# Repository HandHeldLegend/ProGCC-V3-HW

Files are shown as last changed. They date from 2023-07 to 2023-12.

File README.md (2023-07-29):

# ProGCC V3 HW
This is the official Github page for the ProGCC V3 hardware from Hand Held Legend.

## PCB Design License
<br />This PCB design (includes the layout of traces, footprints, and PCB board layout) is licensed under a <a rel="license" href="http://creativecommons.org/licenses/by-nc-sa/3.0/">Creative Commons Attribution-NonCommercial-ShareAlike 3.0 Unported License</a>.

## PCB Schematic License
This PCB schematic is licensed under a <a rel="license" href="https://ohwr.org/cern_ohl_s_v2.pdf">CERN-OHL-S Strongly Reciprocal License</a>.<br>
It contains elements derived from [PhobGCC Hardware](https://github.com/PhobGCC/PhobGCC-HW/) including the rumble schematic and choice of ADCs.

## Shop Links
- [TBA](https://handheldlegend.com)

## Detailed Information
All of our guides on assembly, updating the firmware, and operation
are listed on [our Wiki page linked here](https://wiki.handheldlegend.com).

## Features
- TBA

## Attributions
- Partial trace layout work and initial prototyping performed by [Esca](https://github.com/ESCA47/).
- Main PCB, button board PCB, and bulk schematic designed by Mitch Cairns.
- Rumble schematic derived from work created by the [PhobGCC Team](https://github.com/PhobGCC/).

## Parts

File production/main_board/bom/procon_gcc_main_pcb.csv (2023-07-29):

Id | Designator | Footprint | Quantity | Designation | Supplier and ref
1 | SW4 | TS35CA | 1 | TS35CA
2 | U2,U3,U1,U4 | GH39F | 4 | GH39F (Hall SOT23)
3 | R2,R4 | R_0402_1005Metric | 2 | 100R
4 | R29,R30 | R_0402_1005Metric | 2 | 27
5 | L2,L7,L5,L4,L6,L3,L8,L1 | SK6805-EC-15 | 8 | SK6805-EC-15
6 | D1 | D_SOD-123 | 1 | M7C
7 | C6,C5,C14,C7 | C_0603_1608Metric | 4 | 100nF
8 | TP14,TP13,TP15,TP1,TP11,TP4,TP16,TP3,TP2,TP9,TP7,TP8,TP5 | TestPoint_Pad_D1.5mm | 13 | TestPoint
9 | R18,R14,R17,R16,R19,R15 | R_0402_1005Metric | 6 | 1k
10 | U8,U10 | SOIC-8_3.9x4.9mm_P1.27mm | 2 | MCP3002
11 | C10,C12,C11,C9 | C_0603_1608Metric_Pad1.08x0.95mm_HandSolder | 4 | .047u
12 | Q6,Q4,Q5 | SOT-23 | 3 | BSS138
13 | R22 | R_0402_1005Metric | 1 | 330
14 | F3,F2,F1 | Fuse_1206_3216Metric_Pad1.42x1.75mm_HandSolder | 3 | Fuse
15 | R7,R6,R11,R12,R13,R10 | R_0603_1608Metric_Pad0.98x0.95mm_HandSolder | 6 | 1k
16 | Q3,Q2 | SOT-23 | 2 | Q_NMOS_GSD
17 | C1,C17,C18,C21,C22,C13 | C_0402_1005Metric | 6 | 100n
18 | U6 | QFN-56-1EP_7x7mm_P0.4mm_EP3.2x3.2mm | 1 | RP2040
19 | C19 | C_0402_1005Metric | 1 | 1u
20 | D4,D2 | D_SOD-323_HandSoldering | 2 | CUS08F30
21 | R5,R21,R1,R3 | R_0402_1005Metric | 4 | 10k
22 | C8 | C_0603_1608Metric | 1 | 10u
23 | Y1 | Resonator_SMD_Murata_CSTxExxV-3Pin_3.0x1.1mm | 1 | Crystal_GND3
24 | C3 | CP_EIA-3216-18_Kemet-A | 1 | 47uF 6.3v
25 | U7 | SOT-23 | 1 | LP3986-33B3F
26 | SW2,SW1 | GL18 | 2 | GL18_SW
27 | REF** | HHL_Logo | 1 | HHL_Logo
28 | SW3 | SW_TS-1187A-B-A-B | 1 | TS-1187A-B-A-B
29 | C2,C4 | C_0603_1608Metric | 2 | 2.2uF
30 | J3 | molex_5051101492_14P | 1 | To Button Board
31 | Q1 | SOT-23 | 1 | Q_PMOS_GDS
32 | J9 | Shou Han Type-C 24P QCHT | 1 | USB_C_Receptacle
33 | U9 | SOIC-8_5.23x5.23mm_P1.27mm | 1 | W25Q128JVS
34 | U11,U5 | LGA14 | 2 | ST_LSM6
35 | R9,R8 | R_0603_1608Metric_Pad0.98x0.95mm_HandSolder | 2 | 5.1k
36 | R20 | R_0402_1005Metric | 1 | 500K

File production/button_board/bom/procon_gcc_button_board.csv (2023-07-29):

# | Reference | Qty | Value | Footprint | DNP | MPN
1 | D1, D2, D3, D4, D5, D6 | 6 | BAS16VY,115 | progcc_v3:SOT-363_SC-70-6
2 | J1 | 1 | To Button Board | progcc_v3:molex_5051101492_14P
3 | J2 | 1 | bumpers | progcc_v3:molex_5034800540 |  | molex_5034800540
4 | L1, L2, L3, L4, L5, L6, L7, L8, L9, L10, L11, L12 | 12 | SK6805-EC-15 | progcc_v3:SK6805-EC-15
5 | SW1, SW2, SW3, SW4 | 4 | TL3315NF100Q | progcc_v3:TL3315NFxxxQ
6 | SW5, SW6, SW7, SW8 | 4 | BPAD | progcc_v3:progcc_bpad

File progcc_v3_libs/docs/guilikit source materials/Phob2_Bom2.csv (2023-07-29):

Designator | Footprint | Quantity | Value | LCSC Part #
C14, C15 | C_0402_1005Metric | 2 | 27p | C1557
C16, C18 | C_0805_2012Metric | 2 | 10u | C15850
C17, C19, C20, C22, C24, C25, C26, C27, C28, C29, C30, C31, C32 | C_0402_1005Metric | 13 | 100n | C1525
C21, C23 | C_0402_1005Metric | 2 | 1u | C52923
C3, C4, C5, C6, C7, C8 | C_0603_HandSoldering | 6 | 0.047u | C1622
D1 | D_SOD-123 | 1 | MBR0520 | C908230
D2 | D_SOD-123 | 1 | M7C | C8598
F1 | Fuse_1206_3216Metric | 1 | Fuse | C69680
J8 | USB_Micro-B_Amphenol_10118194_Horizontal | 1 | USB_B_Micro | C132563
Q1, Q3 | SOT-23 | 2 | Q_NMOS_GSD | C20917
Q2 | SOT-23 | 1 | Q_PMOS_GDS | C15127
R1, R2, R7, R8, R9 | R_0402_1005Metric | 5 | 180 | C38941
R10, R19, R24, R25 | R_0402_1005Metric | 4 | 316 | C159037
R11, R12 | R_0603_1608Metric_Pad0.98x0.95mm_HandSolder | 2 | 100R | C22775
R13, R14, R15 | R_0603_1608Metric_Pad0.98x0.95mm_HandSolder | 3 | 10k | C25804
R16, R18 | C_0402_1005Metric | 2 | 1k | C11702
R20, R21 | C_0402_1005Metric | 2 | 27 | C226392
R3, R4, R5, R6 | R_0603_1608Metric_Pad0.98x0.95mm_HandSolder | 4 | 2k | C22975
S1 | SW_TS-1187A-B-A-B | 1 | BOOTSEL | C318884
U1, U3 | SOIC-8_3.9x4.9mm_P1.27mm | 2 | MCP3202 | C56997
U10, U11, U4, U9 | SOT-23 | 4 | DRV5055A2xDBZxQ1 | C266128
U6 | SOT-223-3_TabPin2 | 1 | AMS1117-3.3 | C6186
U7 | SOIC-8_5.23x5.23mm_P1.27mm | 1 | W25Q128JVS | C97521
U8 | RP2040-QFN-56 | 1 | RP2040 | C2040
Y1 | Crystal_SMD_3225-4Pin_3.2x2.5mm | 1 | Crystal_GND24 | C403945

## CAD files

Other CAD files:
progcc_v3_libs/docs/guilikit source materials/GL18 GuliKit Electromagnetic joystick PCB package library/GL18 Joystick.DWG

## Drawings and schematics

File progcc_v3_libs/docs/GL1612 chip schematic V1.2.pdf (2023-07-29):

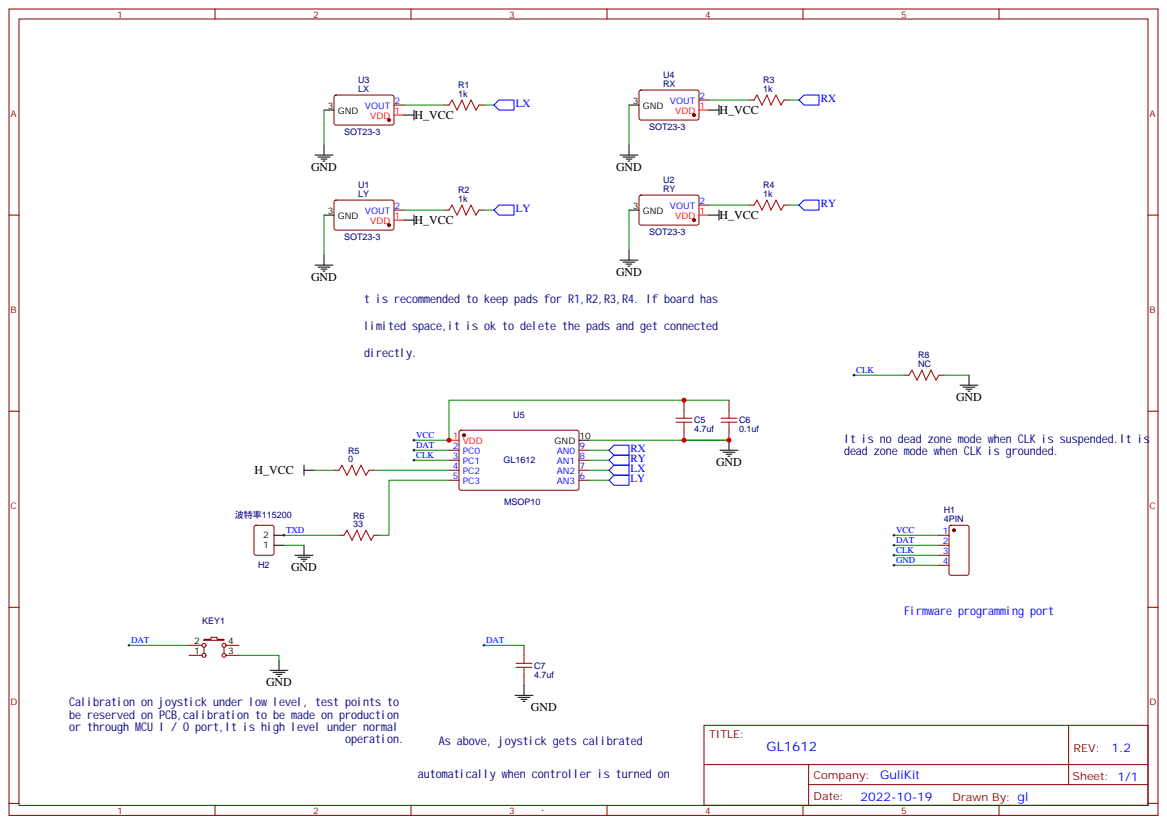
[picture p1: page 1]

t is recommended to keep pads for R1,R2,R3,R4. If board has

limited space,it is ok to delete the pads and get connected

It is no dead zone mode when CLK is suspended.It is
dead zone mode when CLK is grounded.

Calibration on joystick under low level, test points to
be reserved on PCB,calibration to be made on production
or through MCU I / O port,It is high level under normal

As above, joystick gets calibrated

automatically when controller is turned on

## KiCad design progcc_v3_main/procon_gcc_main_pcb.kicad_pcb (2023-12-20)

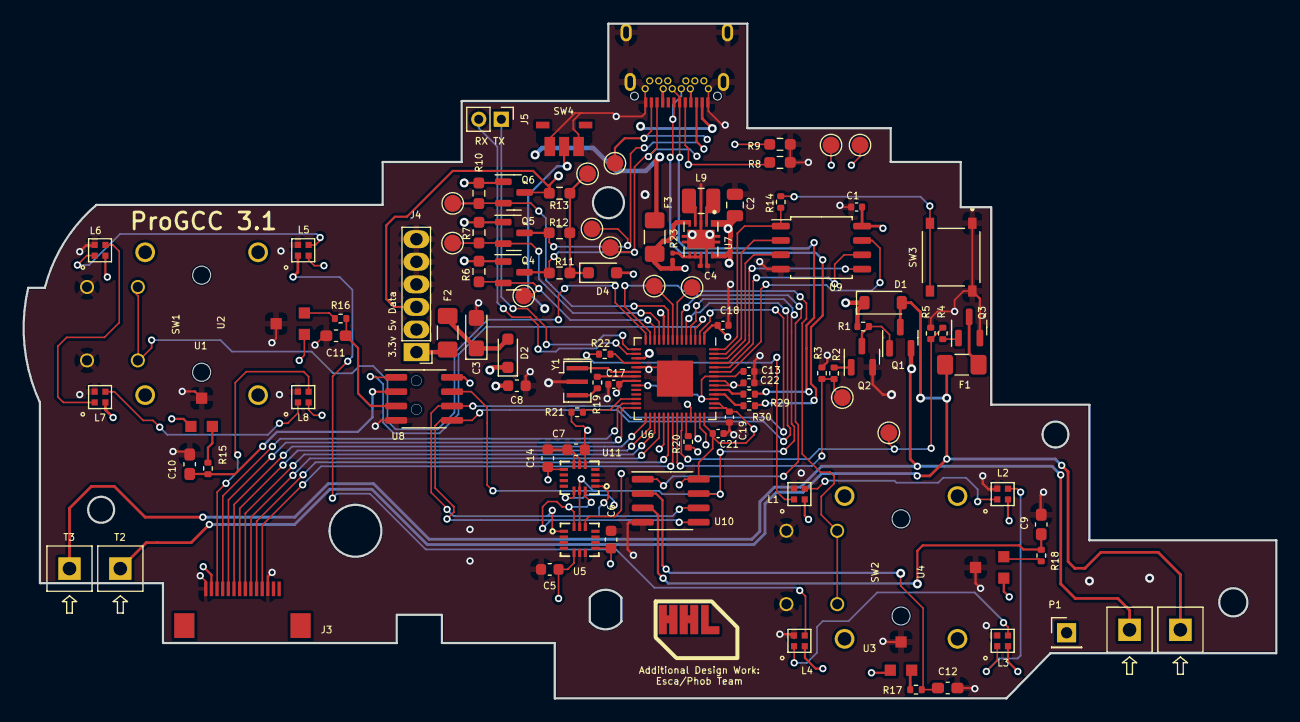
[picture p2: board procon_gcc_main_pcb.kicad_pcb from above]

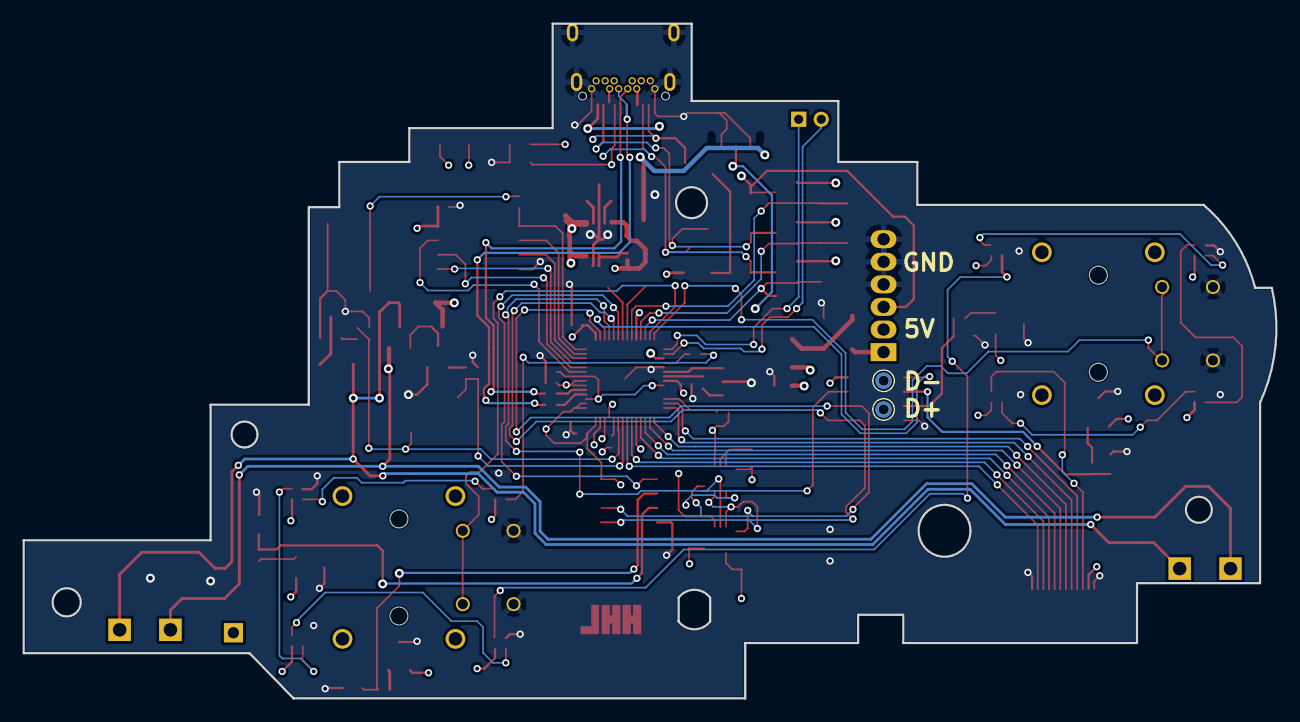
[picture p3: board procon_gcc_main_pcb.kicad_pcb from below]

Board: 4 copper layers, 110.9 x 59.7 mm, 105 parts (2 on the bottom side), 84 nets.

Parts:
C1, C13, C17, C18, C21, C22: 100n; C_0402_1005Metric
C2: 10uF; C_0805_2012Metric
C3: 47uF 6.3v; CP_EIA-3216-18_Kemet-A
C4: 100n; C_0201_0603Metric
C5, C6, C7, C14: 100nF; C_0603_1608Metric
C8: 10u; C_0603_1608Metric
C9, C10, C11, C12: .047u; C_0603_1608Metric_Pad1.08x0.95mm_HandSolder
C19: 1u; C_0402_1005Metric
D1: M7C; D_SOD-123
D2, D4: CUS08F30; D_SOD-323_HandSoldering
F1, F2, F3: Fuse; Fuse_1206_3216Metric_Pad1.42x1.75mm_HandSolder
J3: To Button Board; molex_5051101492_14P
J4: Conn_01x06_Female; GCC_Header_Straight_1x06_Pitch2.00mm
J5: Conn_01x02_Pin; PinHeader_1x02_P2.00mm_Vertical
J9: USB_C_Receptacle; Shou Han Type-C 24P QCHT
L1, L2, L3, L4, L5, L6, L7, L8: SK6805-EC-15
L9: 1.3A 2.2uH ±20% 80mΩ; L_1008_2520Metric
P1: Endpoint; PinHeader_1x01_P2.54mm_Vertical
Q1: Q_PMOS_GDS; SOT-23
Q2, Q3: Q_NMOS_GSD; SOT-23
Q4, Q5, Q6: BSS138; SOT-23
R1, R3, R5, R21: 10k; R_0402_1005Metric
R2, R4: 100R; R_0402_1005Metric
R6, R7, R10, R11, R12, R13: 1k; R_0603_1608Metric_Pad0.98x0.95mm_HandSolder
R8, R9: 5.1k; R_0603_1608Metric_Pad0.98x0.95mm_HandSolder
R14, R15, R16, R17, R18, R19: 1k; R_0402_1005Metric
R20: 500K; R_0402_1005Metric
R22: 330; R_0402_1005Metric
R23: 100; R_0201_0603Metric
R29, R30: 27; R_0402_1005Metric
SW1, SW2: GL18_SW; GL18
SW3: TS-1187A-B-A-B; SW_TS-1187A-B-A-B
SW4: TS35CA
T1, T2, T3, T4: 36-8730; KS_8730
TP1, TP2, TP3, TP4, TP5, TP6, TP7, TP8, TP9, TP10, TP11, TP12, TP14, TP15, TP16: TestPoint; TestPoint_Pad_D1.5mm
U1, U2, U3, U4: GH39F (Hall SOT23); GH39F
U5, U11: ST_LSM6; LGA14
U6: RP2040; QFN-56-1EP_7x7mm_P0.4mm_EP3.2x3.2mm
U7: TPS630001RCR; VREG_V62_16624-01YE
U8, U10: MCP3002; SOIC-8_3.9x4.9mm_P1.27mm
U9: W25Q128JVS; SOIC-8_5.23x5.23mm_P1.27mm
Y1: Crystal_GND3; Resonator_SMD_Murata_CSTxExxV-3Pin_3.0x1.1mm

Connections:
+1V1: C13.2, U6.23 (DVDD), U6.45 (VREG_VOUT), U6.50 (DVDD)
+3.3V_PRE: F2.1, J4.1, J9.A2 (TX1+), J9.B2 (TX2+)
+3V3: C1.1, C2.1, C5.2, C6.2, C7.2, C8.2, C14.2, C17.1, C18.1, C19.1, C21.2, C22.2, D4.2 (A), J3.2, L1.2 (VDD), L2.2 (VDD), L3.2 (VDD), L4.2 (VDD), L5.2 (VDD), L6.2 (VDD), L7.2 (VDD), L8.2 (VDD), Q4.1 (G), Q5.1 (G), Q6.1 (G), R6.1, R7.1, R10.1, R21.1, TP14.1, U1.1 (VDD), U2.1 (VDD), U3.1 (VDD), U4.1 (VDD), U5.5 (VDDIO), U5.8 (VDD), U6.1 (IOVDD), U6.10 (IOVDD), U6.22 (IOVDD), U6.33 (IOVDD), U6.42 (IOVDD), U6.43 (ADC_AVDD), U6.44 (VREG_IN), U6.48 (USB_VDD), U6.49 (IOVDD), U7.1 (VOUT), U7.10 (FB), U8.8 (VDD/VREF), U9.8 (VCC), U10.8 (VDD/VREF), U11.5 (VDDIO), U11.8 (VDD)
+5V_PRE: F3.1, J4.2, J9.A4 (VBUS), J9.A9 (VBUS), J9.B4 (VBUS), J9.B9 (VBUS)
+VCC: D1.1 (K), D2.1 (K), F3.2, Q1.2 (S), R1.2, R23.1, T1.1, T3.1, TP9.1, U7.5 (VIN)
/CC1: J9.A5 (CC1), R8.1
/CC2: J9.B5 (CC2), R9.1
/QSPI_SCLK: U6.52 (QSPI_SCLK), U9.6 (CLK)
/QSPI_SD0: U6.53 (QSPI_SD0), U9.5 (DI(IO0))
/QSPI_SD1: U6.55 (QSPI_SD1), U9.2 (DO(IO1))
/QSPI_SD2: U6.54 (QSPI_SD2), U9.3 (IO2)
/QSPI_SD3: U6.51 (QSPI_SD3), U9.7 (IO3)
/QSPI_SS: R14.1, U6.56 (QSPI_SS), U9.1 (~CS)
/RUN: R21.2, U6.26 (RUN)
/~USB_BOOT: R14.2, SW3.C, SW3.D
BUTTON_RGB: J3.3, L8.3 (DOUT)
D+: J9.A6 (D+), J9.B6 (D+), R29.1, TP12.1
D-: J9.A7 (D-), J9.B7 (D-), R30.1, TP10.1
GND: C1.2, C2.2, C3.2, C4.1, C5.1, C6.1, C7.1, C8.1, C9.1, C10.1, C11.1, C12.1, C13.1, C14.1, C17.2, C18.2, C19.2, C21.1, C22.1, J3.1, J3.12, J4.4, J4.5, J4.6, J9.A1 (GND), J9.A12 (GND), J9.B1 (GND), J9.B12 (GND), J9.S1 (SHIELD), L1.4 (GND), L2.4 (GND), L3.4 (GND), L4.4 (GND), L5.4 (GND), L6.4 (GND), L7.4 (GND), L8.4 (GND), Q2.2 (S), Q3.2 (S), R3.1, R5.1, R8.2, R9.2, SW1.S3 (3), SW1.S4 (4), SW2.S3 (3), SW2.S4 (4), SW3.A, SW3.B, SW4.1, SW4.3, U1.3 (GND), U2.3 (GND), U3.3 (GND), U4.3 (GND), U5.2 (SDx), U5.3 (SCx), U5.6 (GNDIO), U5.7 (GND), U6.19 (TESTEN), U6.57 (GND), U7.3 (PGND), U7.9 (GND), U7.11 (EP), U8.4 (VSS), U9.4 (GND), U10.4 (VSS), U11.2 (SDx), U11.3 (SCx), U11.6 (GNDIO), U11.7 (GND), Y1.2
GP1: TP15.1, U6.7 (GPIO5)
GP2: TP16.1, U6.8 (GPIO6)
IMU0_CS: U5.12 (CS), U6.40 (GPIO28_ADC2)
IMU1_CS: U6.41 (GPIO29_ADC3), U11.12 (CS)
LADC_CS: U6.3 (GPIO1), U8.1 (~CS/SHDN)
LS_BUTTON: SW1.S1 (1), SW1.S2 (2), U6.14 (GPIO11)
LX: C10.2, R15.2, U8.2 (CH0)
LY: C11.2, R16.2, U8.3 (CH1)
MODE_BUTTON: SW4.2, U6.17 (GPIO14)
NFC: J3.13, J3.14
N_CLOCK: J9.A3 (TX1-), J9.B3 (TX2-), Q5.3 (D), R12.2, TP6.1
N_CLOCK_3.3: Q5.2 (S), R7.2, TP2.1, U6.11 (GPIO8)
N_DATA: J4.3, J9.A11 (RX2+), J9.B11 (RX1+), Q6.3 (D), R13.2, TP7.1
N_DATA_3.3: Q6.2 (S), R10.2, TP3.1, U6.9 (GPIO7)
N_LATCH: J9.A10 (RX2-), J9.B10 (RX1-), Q4.3 (D), R11.2, TP5.1
N_LATCH_3.3: Q4.2 (S), R6.2, TP1.1, U6.12 (GPIO9)
unnamed: C3.1, D2.2 (A), F2.2
unnamed: L1.3 (DOUT), L2.1 (DIN)
unnamed: L2.3 (DOUT), L3.1 (DIN)
unnamed: L3.3 (DOUT), L4.1 (DIN)
unnamed: L5.3 (DOUT), L6.1 (DIN)
unnamed: L6.3 (DOUT), L7.1 (DIN)
unnamed: L7.3 (DOUT), L8.1 (DIN)
unnamed: Q1.1 (G), Q2.3 (D), R1.1
unnamed: Q2.1 (G), R2.2
unnamed: F1.2, Q3.3 (D)
unnamed: Q3.1 (G), R4.2
unnamed: R19.1, Y1.3
unnamed: R15.1, U1.2 (VOUT)
unnamed: R16.1, U2.2 (VOUT)
unnamed: R17.1, U3.2 (VOUT)
unnamed: R18.1, U4.2 (VOUT)
unnamed: R30.2, U6.46 (USB_DM)
unnamed: R29.2, U6.47 (USB_DP)
unnamed: C4.2, R23.2, U7.6 (EN), U7.7 (PS/SYNC), U7.8 (VINA)
unnamed: L9.1, U7.4 (L1)
unnamed: L9.2, U7.2 (L2)
Push_A: J3.4, U6.27 (GPIO16)
Push_B: J3.6, U6.29 (GPIO18)
Push_C: J3.9, U6.32 (GPIO21)
Push_D: J3.10, U6.34 (GPIO22)
RADC_CS: U6.6 (GPIO4), U10.1 (~CS/SHDN)
RGB_OUT: R22.2, U6.18 (GPIO15)
RS_BUTTON: SW2.S1 (1), SW2.S2 (2), U6.13 (GPIO10)
RUMBLE: R4.1, R5.2, TP11.1, U6.37 (GPIO25)
RUMBLE-: D1.2 (A), F1.1, Q1.3 (D), T2.1, T4.1
RX: C12.2, R17.2, U10.2 (CH0)
RY: C9.2, R18.2, U10.3 (CH1)
R_BRAKE: R2.1, R3.2, TP8.1, U6.36 (GPIO24)
SHARED_PU: D4.1 (K), R11.1, R12.1, R13.1, TP4.1
SL_RGB: L1.1 (DIN), R22.1
SPI_CK: U5.13 (SCL), U6.4 (GPIO2), U8.7 (CLK), U10.7 (CLK), U11.13 (SCL)
SPI_RX: U5.1 (SDO), U6.2 (GPIO0), U8.6 (DOUT), U10.6 (DOUT), U11.1 (SDO)
SPI_TX: U5.14 (SDA), U6.5 (GPIO3), U8.5 (DIN), U10.5 (DIN), U11.14 (SDA)
SR_RGB: L4.3 (DOUT), L5.1 (DIN)
Scan_A: J3.11, U6.35 (GPIO23)
Scan_B: J3.8, U6.31 (GPIO20)
Scan_C: J3.5, U6.28 (GPIO17)
Scan_D: J3.7, U6.30 (GPIO19)
TOUCH_IN: R20.1, U6.38 (GPIO26_ADC0)
TOUCH_OUT: P1.1, R20.2, U6.39 (GPIO27_ADC1)
UART0_RX: J5.2, U6.16 (GPIO13)
UART0_TX: J5.1, U6.15 (GPIO12)
XTAL_IN: U6.20 (XIN), Y1.1
XTAL_OUT: R19.2, U6.21 (XOUT)

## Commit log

2023-07-29 remove D3
    [procon_gcc_button_board-B_Courtyard.gbr, procon_gcc_button_board-B_Cu.gbr, procon_gcc_button_board-B_Fab.gbr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]
2023-09-17 Fix right stick LED group
    [procon_gcc_main_pcb.kicad_sch]
2023-12-20 Update regulator
    [procon_gcc_button_board.kicad_pcb, procon_gcc_button_board.kicad_sch, procon_gcc_main_pcb.kicad_pcb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]
